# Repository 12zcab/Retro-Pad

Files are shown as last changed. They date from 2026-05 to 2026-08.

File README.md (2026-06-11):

# Retro-Pad
What happens if a keyboard can emulate Retro Stuff?
Yah its just a simple keyboard but include a 4inch tft and speaker for Retro Emulation and Designed for myself.

## Tinkercad Link
https://www.tinkercad.com/things/bjJYySNUwrn-blekeyboard-esp32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
## Zine Page Design
https://www.figma.com/design/CGgY6SRriEGCdJu8L95h5M/Retro-Pad-Zine-Page?node-id=0-1&t=7zGqFnisPlWxRSIn-1
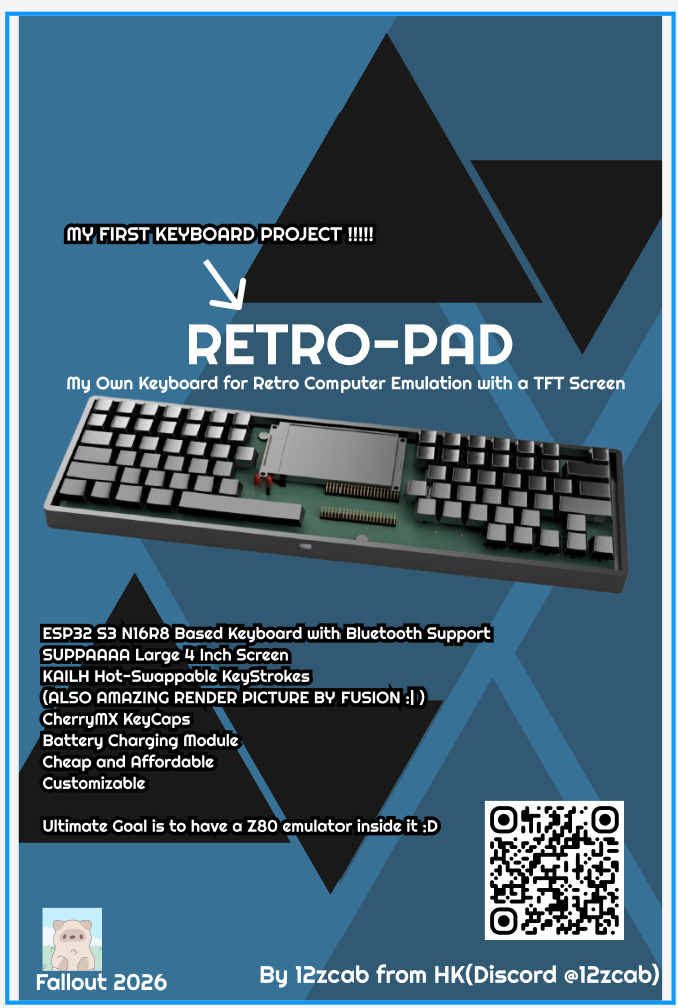
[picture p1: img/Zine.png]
Zine

## Images
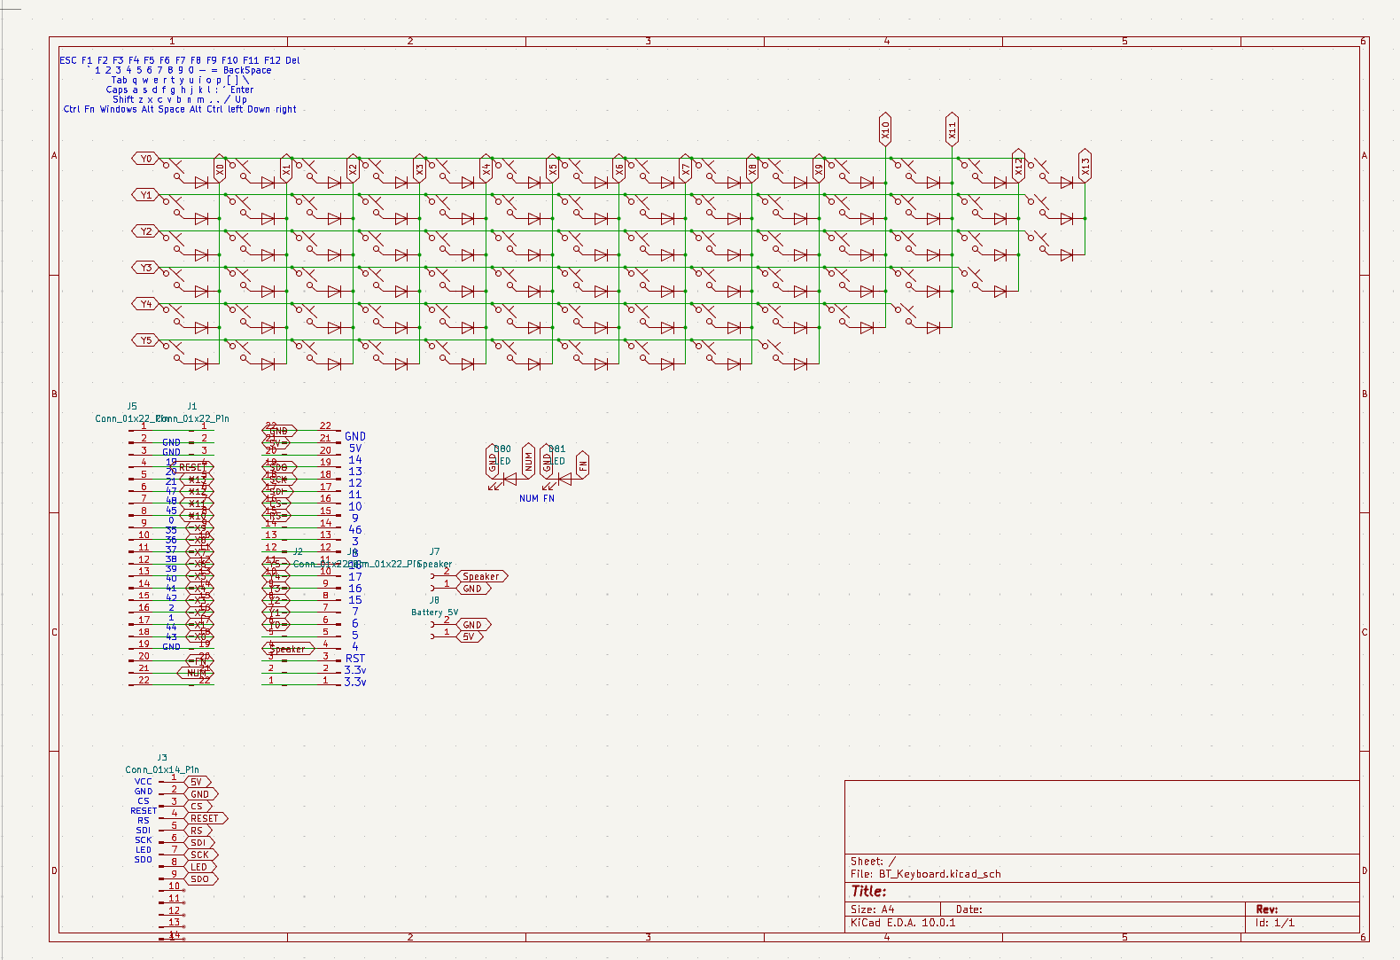
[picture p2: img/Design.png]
Design

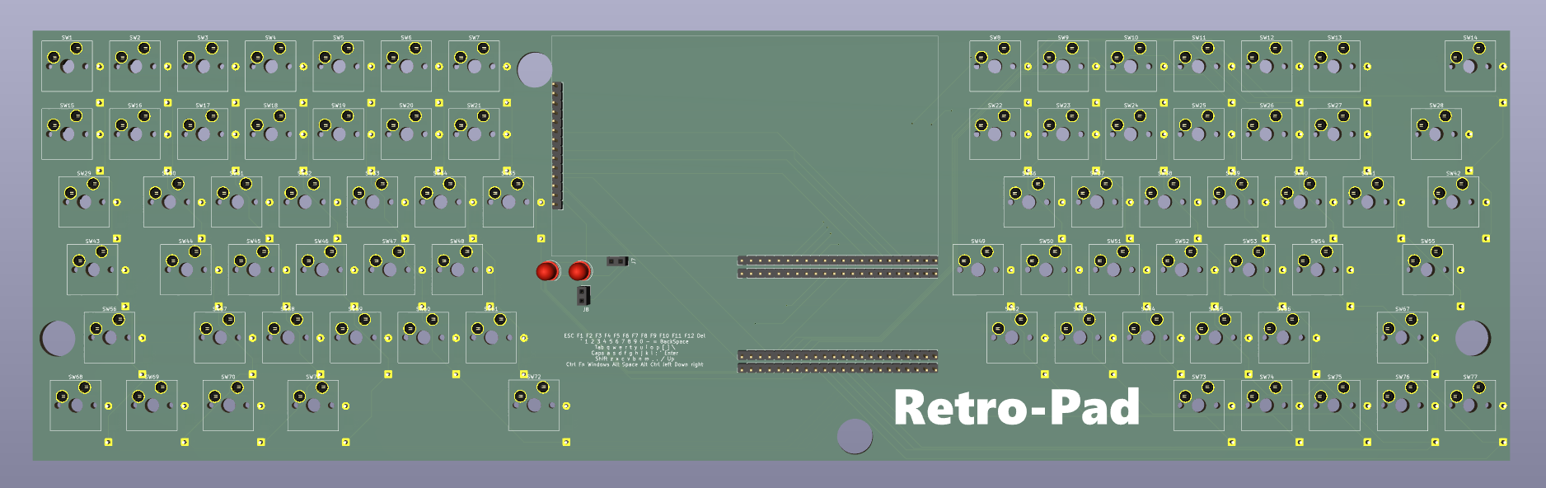
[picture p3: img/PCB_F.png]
PCB_F

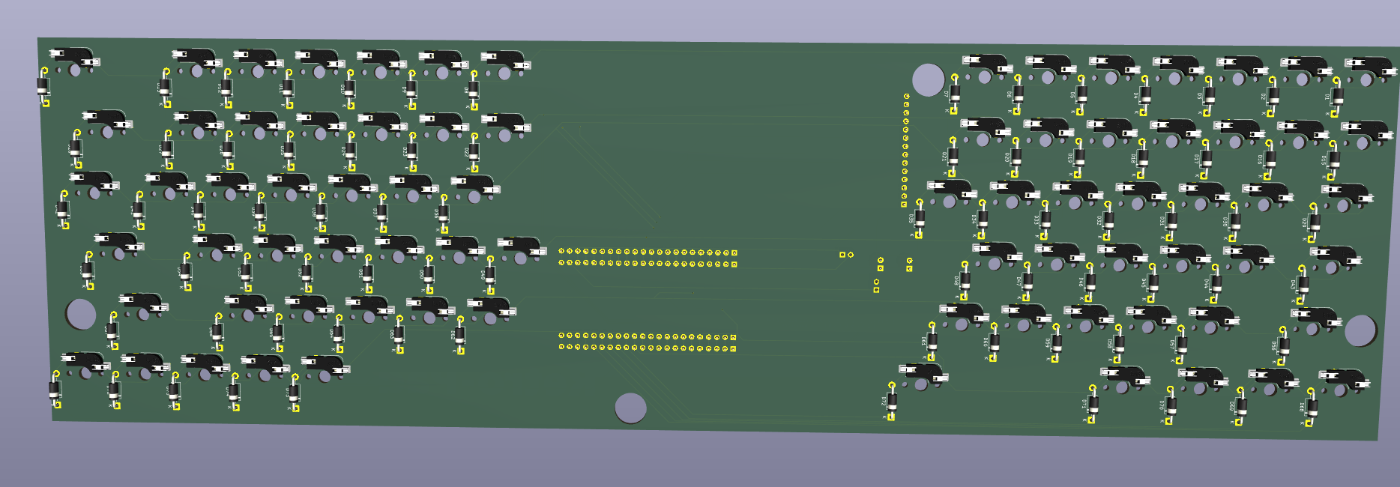
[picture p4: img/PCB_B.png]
PCB_B

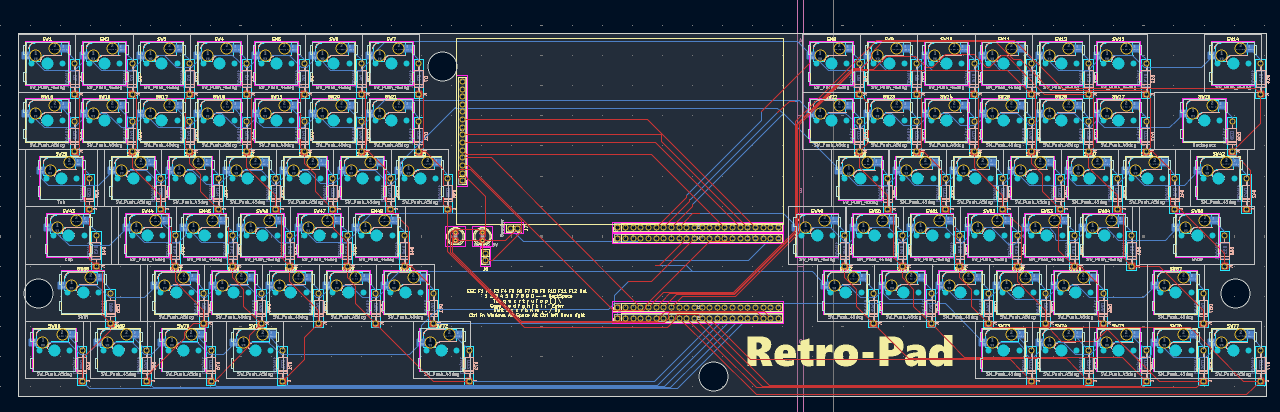
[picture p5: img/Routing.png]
Routing

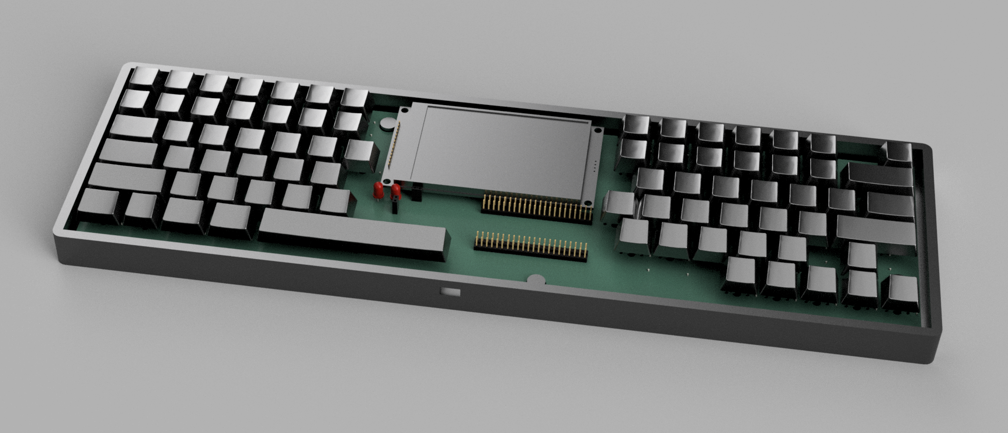
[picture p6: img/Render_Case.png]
Case


## Notes
Erm the Emulator Part is not yet programmed as i haven't build it irl yet
I will work on it as I receive the grant to buy the ESP32
Also as i like Looking at PCBs so the case will be really simple

## Why I build this?
1.My Current Keyboard is DUMB
2.I think i like the touch of the 高特(erm in direct translation, High Special) Keystrokes
3.I also like to emulate 8086 or z80s with my pi and keyboard and a hdmi screen but i realized a single esp32 could have done all things in a single PCB

## What it can do?
1.Bluetooth/USB keyboard support
2.Configurable Macro Support
3.Key Layout Remap Support
4.Emulate Z80 CP/M :D
5.may be also as a mini Piano?(Erm yah cuz why not?)

## Component List
(For More Details,Please Refer to the BOM.csv.)
| Name | SpecName | Usage | Quantities |
|---|---|---|---|
| KeyStrokes | For My Self,高特青軸 (im not sure what its called in english)| For the Switches on Keyboard!| 77 |
| KeyCaps | Cherry Key Caps | Key Caps that you press on | Depends |
| ESP32 MCU board | ESP32 S3 N16R8 | A controller board that handles the TFT screen display and Bluetooth Communication | 1 |
| TFT Screen | TFT 4inch Screen Module with 14 Pins | A medium size TFT that display the Emulated Content and also Let me reconfigure the Keyboard with GUI | 1 |
| KeyStroke Hot Swappable Sockets | Kailh KeyStroke Sockets | for HotSwappable KeyStrokes!!! | 77 |
| Speaker | 2W3718 Speaker Module | Play Some Funny Sounds with esp32 | 1 |
| LED for Fn and Caps Signal | 5mm diameter THT leds | to show if u have Caps and Fn enabled or disabled. | 2 |
| LiBattery 3.7V | No Specific Name,just any Li Battery that can fit into the case | Any Capacity u want,3000mah suggested | 1 |
| LiBattery 3.7v-5v Protector Board and Charger Board | same as the name | Protecting ur Li-ion Battery from exploding | 1 |

Also prepare some 2.54 Dupont Socket and PinHeaders incase if u may disassemble it or replace some modules.

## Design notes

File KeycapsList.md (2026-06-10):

## 3D printing List and Keycap List
| | R1 | R2 | R3 | R4 |
|---|---|---|---|---|
|U1|Fn Alt Ctrl ArrowL ArrowR ArrowD ZXCVBNM,./ ArrowU|ASDFGHJKL;'|QWERTYUIOP[]|`1234567890-= Esc F1-12 Delete|
|U1.25|Win Alt Ctrl||||
|U1.5|||Tab \||
|U1.75||Caps Lock|||
|U2||||BackSpace|
|U2.25|Shift|Enter|||
|U5.25|Space||||

| | R1 | R2 | R3 | R4 | SUM |
|---|---|---|---|---|---|
|U1|17|11|12|27|67|
|U1.25|3||||3|
|U1.5|||2||2|
|U1.75||1|||1|
|U2||||1|1|
|U2.25|1|1|||2|
|U5.25|1||||1|
|..|..|..|..|..|77|

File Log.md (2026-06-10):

Day1 2/5/2026

Targets:
1.Bluetooth Keyboard Support

2.Music Instrument

3.Simple 8086 or z80 Simulation (Hopefully)

https://github.com/ConstantinoSchillebeeckx/cherry-mx-keycaps

what i have done today:

1. generated the Keylayout.json and used the KB plugin in Kicad to Arrange the Layout of keys
2. decided how am i going to stream the HDMI screen to tft (through UVC and HDMI to USB Capture Card(i found some cheap one))
3. finished the simple Circuit in kicad and layouted some of them in Kicad

Day2 15/5/2026

Finished Kicad Layout and Routing

We will move on to the coding part next time:D

https://item.taobao.com/item.htm?ali\_refid=a3\_430008\_1006%3A1422310143%3AH%3A%2FWxXF5KEPDBl3HD6bqPRiwI%2Fqz1PRZed%3A7e8e3f8b5423678a1f3602527d140b2b\&ali\_trackid=283\_7e8e3f8b5423678a1f3602527d140b2b\&id=889327946362\&mi\_id=0000KfCYVAKBkDPFdWEk\_TIRsJP2s26MLFkTm8Ch3dcCHBo\&mm\_sceneid=1\_0\_1500450081\_0\&priceTId=2100c90417795207132815695e0cf9\&skuId=5917293894029\&spm=a21n57.1.hoverItem.2\&utparam=%7B%22aplus\_abtest%22%3A%2217b833b15ee66eaabd2b4353216af808%22%7D\&xxc=ad\_ztc

https://item.taobao.com/item.htm?abbucket=20\&id=892402646945\&mi\_id=00008PVZair30QEfFiEgqpUfwUhRiykNUhKd\_J1pzu8Z\_iA\&ns=1\&priceTId=2100cff417795213512193519e0d1d\&skuId=5908689555076\&spm=a21n57.1.hoverItem.11\&utparam=%7B%22aplus\_abtest%22%3A%22b225d9c1a26b6233dcdc5695b8bcce75%22%7D\&xxc=taobaoSearch

Day3 23/5/2026

Added the Speaker and Power Module.
Finished Routing the PCB and generated Gerber and Drill Files

Finished a Simple Firmware for testing

Day4 24/5/2026

Redesigned the PCB for Hot-Swappable Keystrokes and routed it.

Wrote some details for readme.md

Also finished the BOM

Rendered 3D image for the PCB

Exported Gerber Files

Exported PCB 3D files

Included the CherryMX KeyCaps from another repo
Erm i think my computer got some problem so i will finish the STL case next time

Day5 26/5/2026

Finished the basic case and also keycap amount table for R1-R4 and U1 to U5.25
Erm as my Space bar is only 5.25U sooooooo i hope it can work without stablizer
(Hopefulyl it will work like:  - _ )and not - \ :DDDDD anybody get it?

Day6 3/6/2026
Requirement Checklist:
1.Update the Photo in Figma DONE
2.Update all the PCB designs in GitHub   DONE
3.Add Zine Photo to Readme.md  DONE  
4.Add mounting holes for the PCB  DONE 
5.Make a Better Case with Fusion (with Text and rounded Edges and also mounting pins for positioning)  DONE

Day7 10/6/2026
Rendered the 3D image with Keycaps
Added Cost for BOM.csv
Resubmitting.

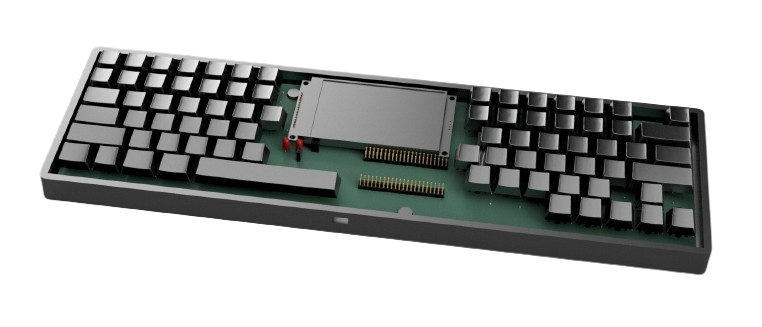
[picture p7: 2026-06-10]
img/RMBG.png

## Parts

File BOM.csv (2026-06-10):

Qty | Value | Link | Quantity Price | Total Item Price in RMB | Total Item Price in USD
77 | 1N4001 Diode | https://item.taobao.com/item.htm?ali_trackid=1_ac852f84a5ddb011c0c889d4550c7625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 | 0.03 | 2.31 | 0.3465
2 | LED | https://item.taobao.com/item.htm?ali_trackid=318_36dd7da80ac5a741d8252891407d112a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 | Not Appliable | 3.77 | 0.5655
1 | ESP32 S3 N16R8 | https://item.taobao.com/item.htm?id=810960494289&from=cart&skuId=5838973348963&upStreamPrice=2430 | 24.3 | 24.3 | 3.645
1 | 4Inch TFT Screen | https://item.taobao.com/item.htm?id=811840045954&from=cart&skuId=5675825499909&upStreamPrice=7542 | 75.62 | 75.62 | 11.343
1 | Speaker | https://item.taobao.com/item.htm?ali_trackid=283_7e8e3f8b5423678a1f3602527d140b2b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 | 5 | 5 | 0.75
1 | Battery 5V | https://item.taobao.com/item.htm?id=892402646945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 | 13 | 13 | 1.95
77 | KeyStroke | https://item.taobao.com/item.htm?id=626986550029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 | Not Appliable | 32.4 | 4.86
77 | KailH KeyStroke Holder | https://item.taobao.com/item.htm?id=633674488792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 | Not Appliable | 15 | 2.25
 | Sum Up |  |  |  | 25.71
 | Estimated Cost with Transporting Cost |  |  |  | 30.852

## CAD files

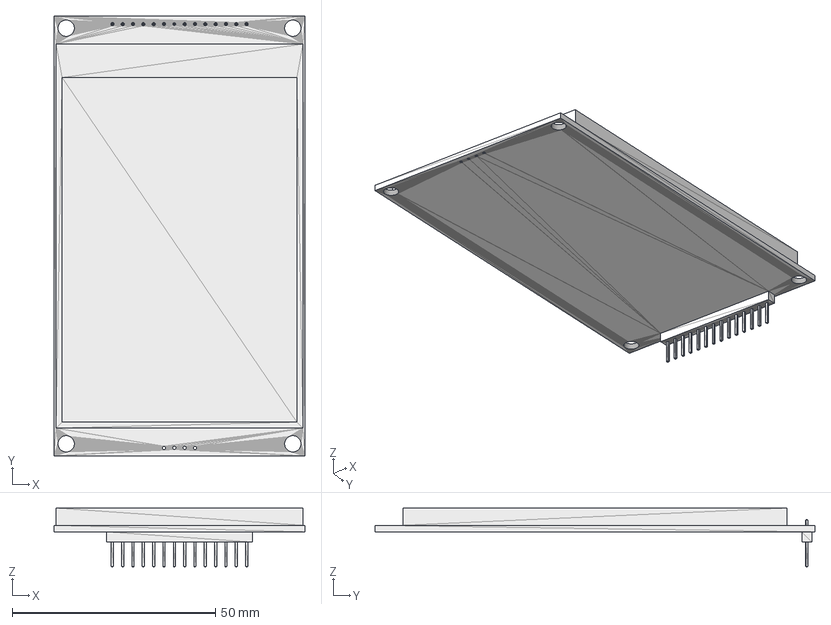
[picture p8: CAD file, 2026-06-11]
3Dmodels/4_0 inch tft.step
61.8 x 108.2 x 14.5 mm

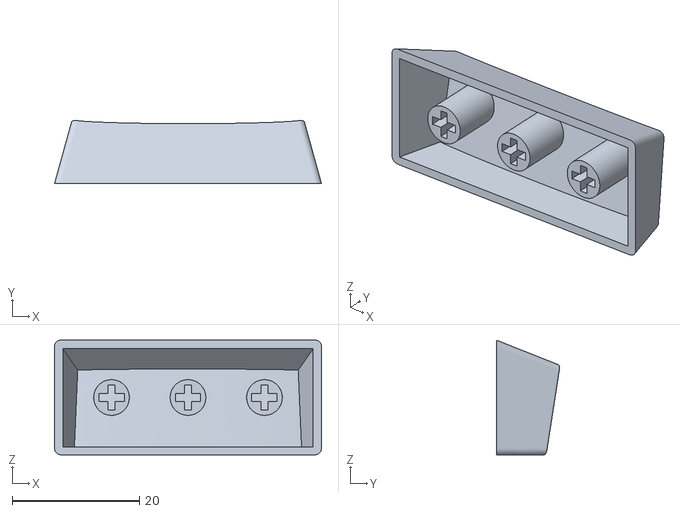
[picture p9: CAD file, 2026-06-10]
3Dmodels/Caps/1x2.25 R1.stl
41.9 x 9.89 x 18.0

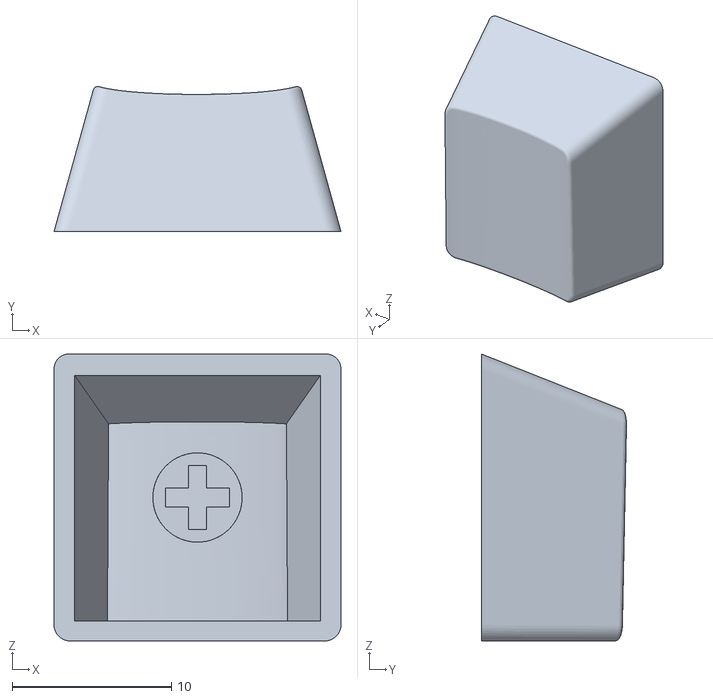
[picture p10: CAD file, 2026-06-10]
3Dmodels/Caps/1x1 R3.stl
18.0 x 9.09 x 18.0

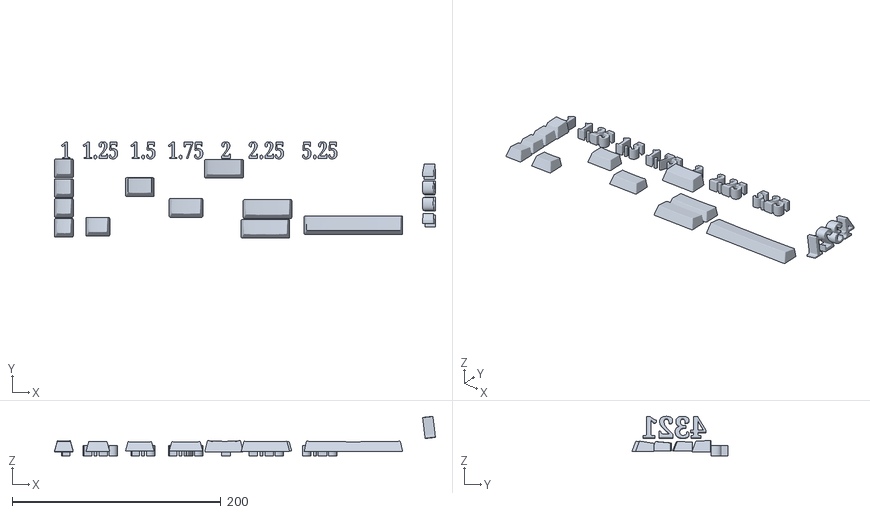
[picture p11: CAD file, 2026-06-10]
3Dmodels/KeyCaps.stl
365.4 x 92.5 x 37.9

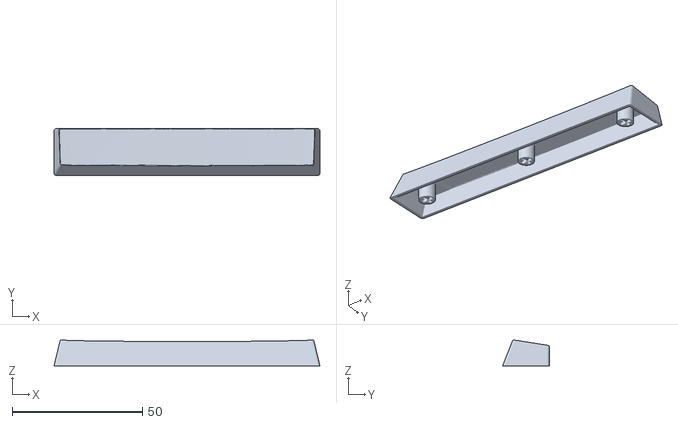
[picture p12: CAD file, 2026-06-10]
3Dmodels/Caps/1x5.25 R1.stl
102.1 x 18.0 x 9.95

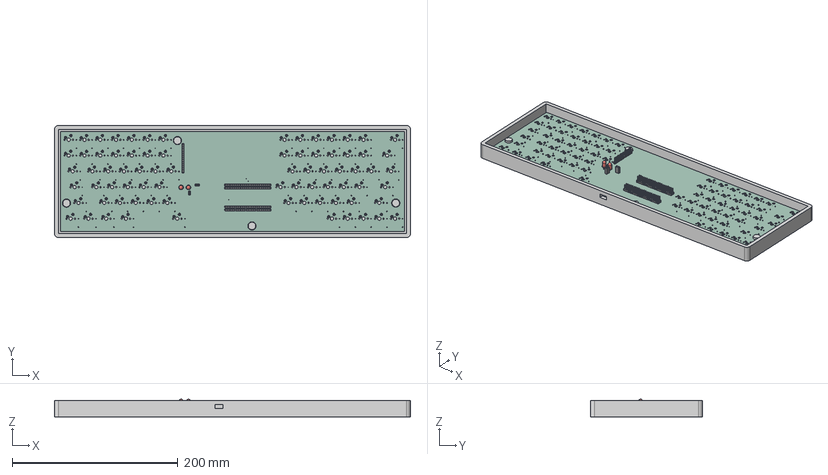
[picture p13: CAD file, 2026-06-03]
3Dmodels/Case.step
429.8 x 135.7 x 21.5 mm
PinSocket_1x02_P2.54mm_Vertical x 2
PinHeader_1x14_P2.54mm_Vertical
LED_D5.0mm x 2
PinHeader_1x22_P2.54mm_Vertical x 4
BT_Keyboard_PCB
D_DO-41_SOD81_P10.16mm_Horizontal x 77
SW_Hotswap_Kailh_MX x 77

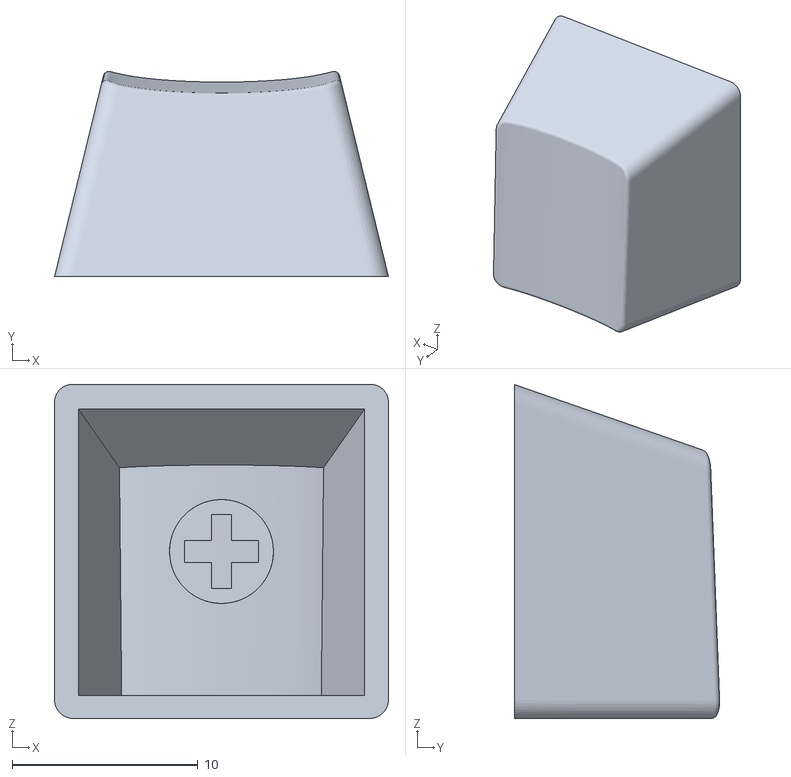
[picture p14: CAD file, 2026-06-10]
3Dmodels/Caps/1x1 R4.stl
18.0 x 11.1 x 18.0

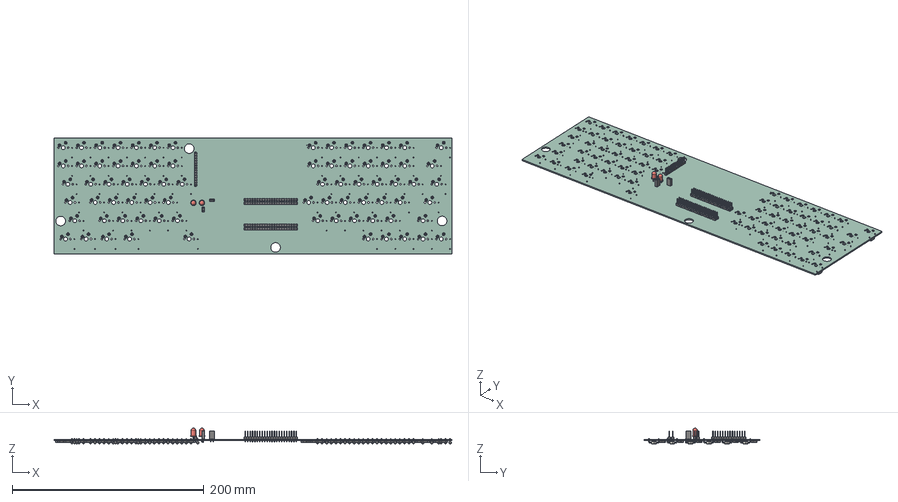
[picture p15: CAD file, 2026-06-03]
3Dmodels/pcb.step
414.8 x 120.7 x 16.5 mm
SW_Hotswap_Kailh_MX x 77
PinSocket_1x02_P2.54mm_Vertical x 2
PinHeader_1x14_P2.54mm_Vertical
LED_D5.0mm x 2
PinHeader_1x22_P2.54mm_Vertical x 4
D_DO-41_SOD81_P10.16mm_Horizontal x 77
BT_Keyboard_PCB

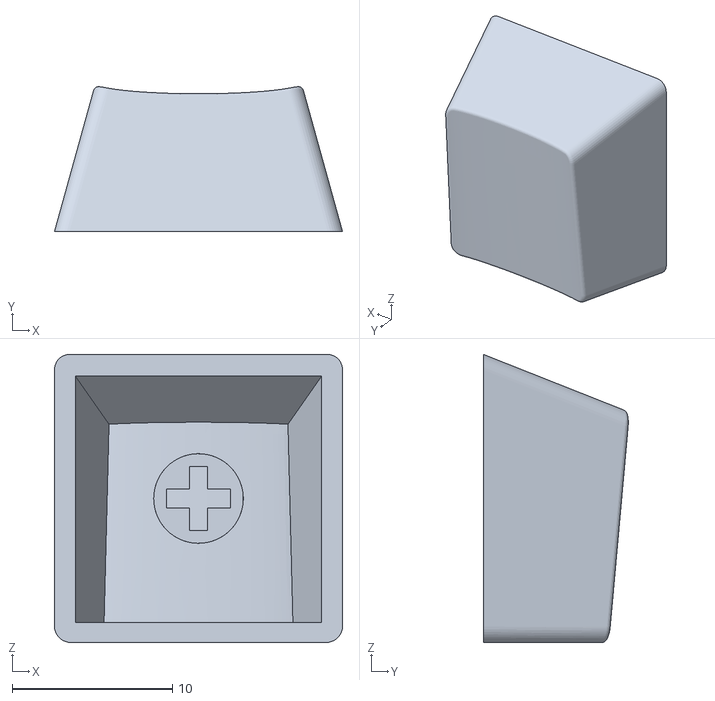
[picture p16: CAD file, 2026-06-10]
3Dmodels/Caps/1x1 R2.stl
18.0 x 9.04 x 18.0

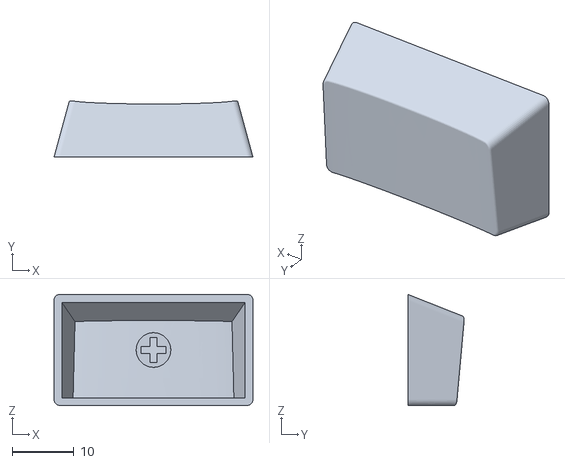
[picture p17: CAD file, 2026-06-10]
3Dmodels/Caps/1x1.75 R2.stl
32.2 x 9.10 x 18.0

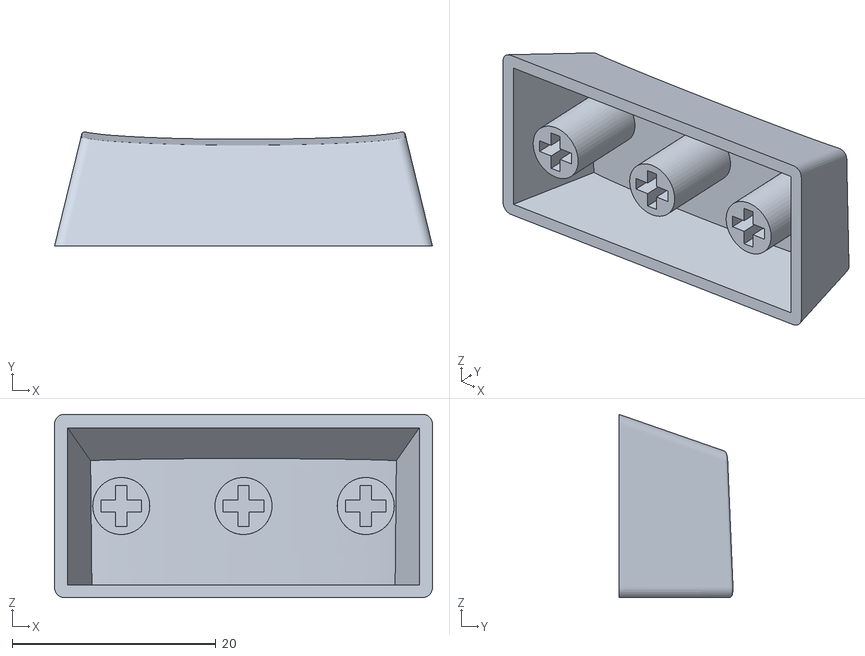
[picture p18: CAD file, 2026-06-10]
3Dmodels/Caps/1x2 R4.stl
37.1 x 11.2 x 18.0

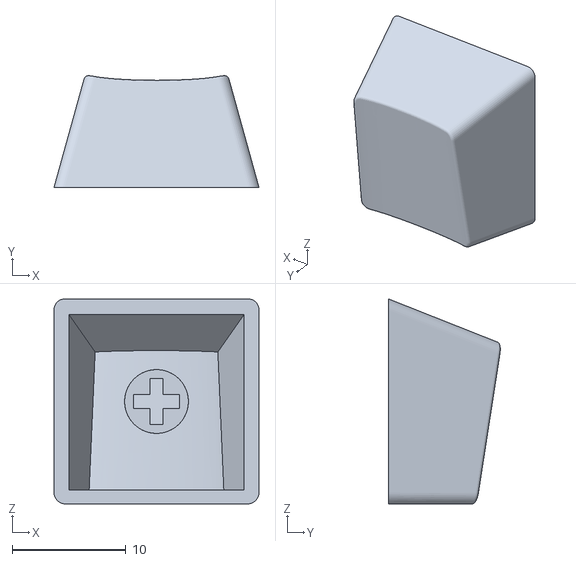
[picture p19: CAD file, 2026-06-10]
3Dmodels/Caps/1x1 R1.stl
18.0 x 9.80 x 18.0

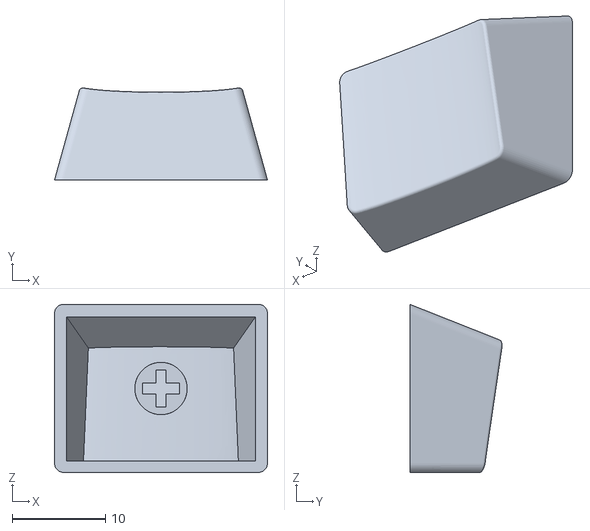
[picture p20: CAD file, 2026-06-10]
3Dmodels/Caps/1x1.25 R1.stl
22.8 x 9.84 x 18.0

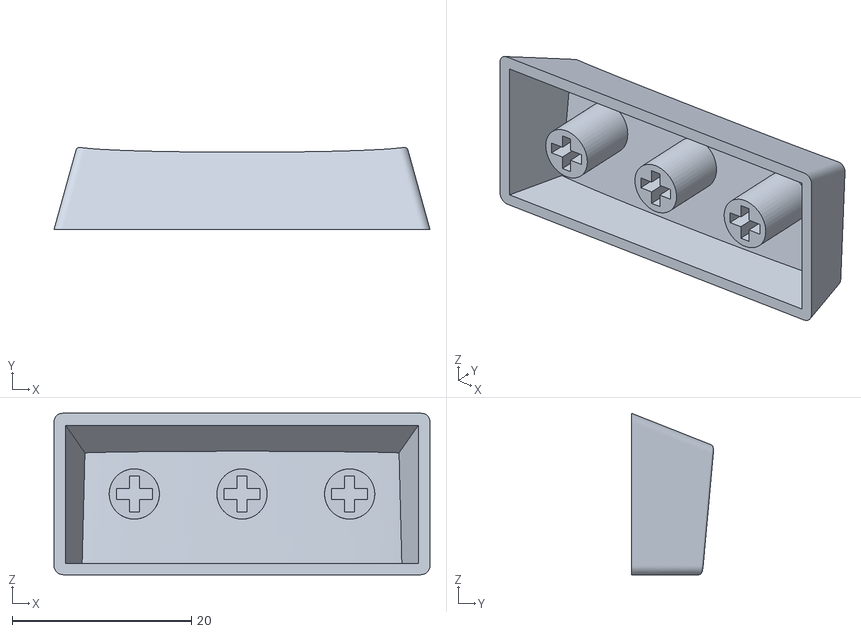
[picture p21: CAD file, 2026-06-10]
3Dmodels/Caps/1x2.25 R2.stl
41.9 x 9.12 x 18.0

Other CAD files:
3Dmodels/Caps/1x1.5 R3.stl
3Dmodels/4_0 inch tft.stl

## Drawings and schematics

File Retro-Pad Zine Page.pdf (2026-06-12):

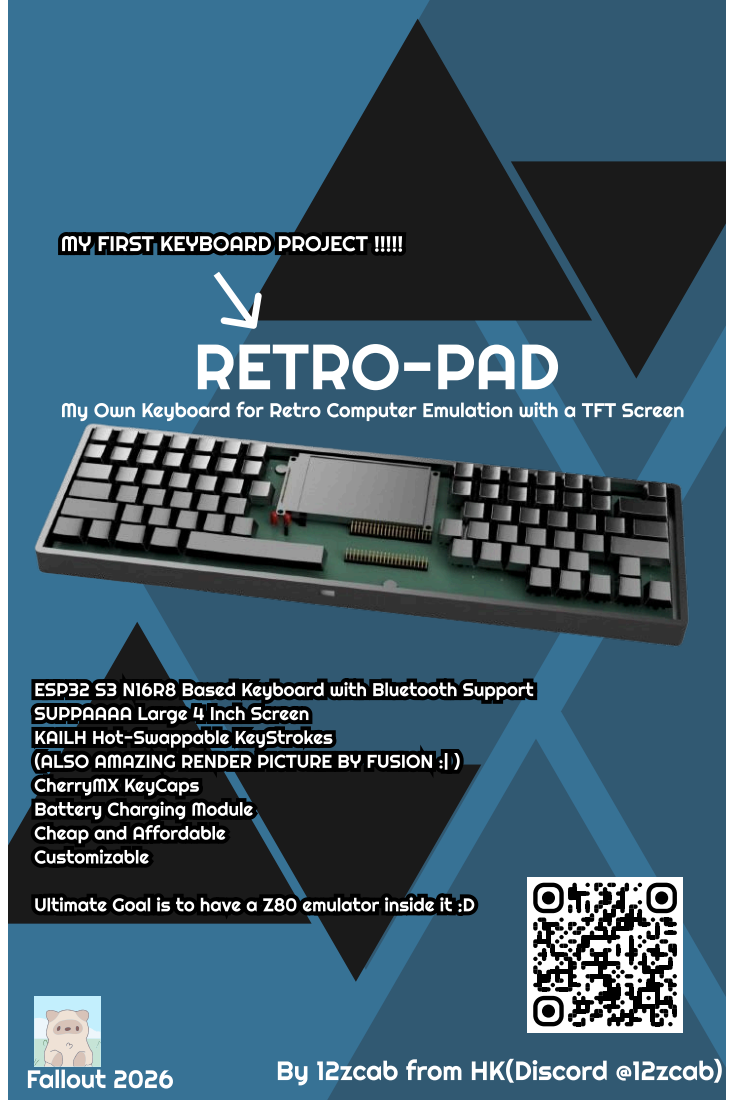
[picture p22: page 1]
Fallout 2026; RETRO-PAD

MY FIRST KEYBOARD PROJECT !!!!!

My Own Keyboard for Retro Computer Emulation with a TFT Screen

ESP32 S3 N16R8 Based Keyboard with Bluetooth Support
SUPPAAAA Large 4 Inch Screen
KAILH Hot-Swappable KeyStrokes
(ALSO AMAZING RENDER PICTURE BY FUSION :| )
CherryMX KeyCaps
Battery Charging Module
Cheap and Affordable
Customizable

Ultimate Goal is to have a Z80 emulator inside it :D

By 12zcab from HK(Discord @12zcab)

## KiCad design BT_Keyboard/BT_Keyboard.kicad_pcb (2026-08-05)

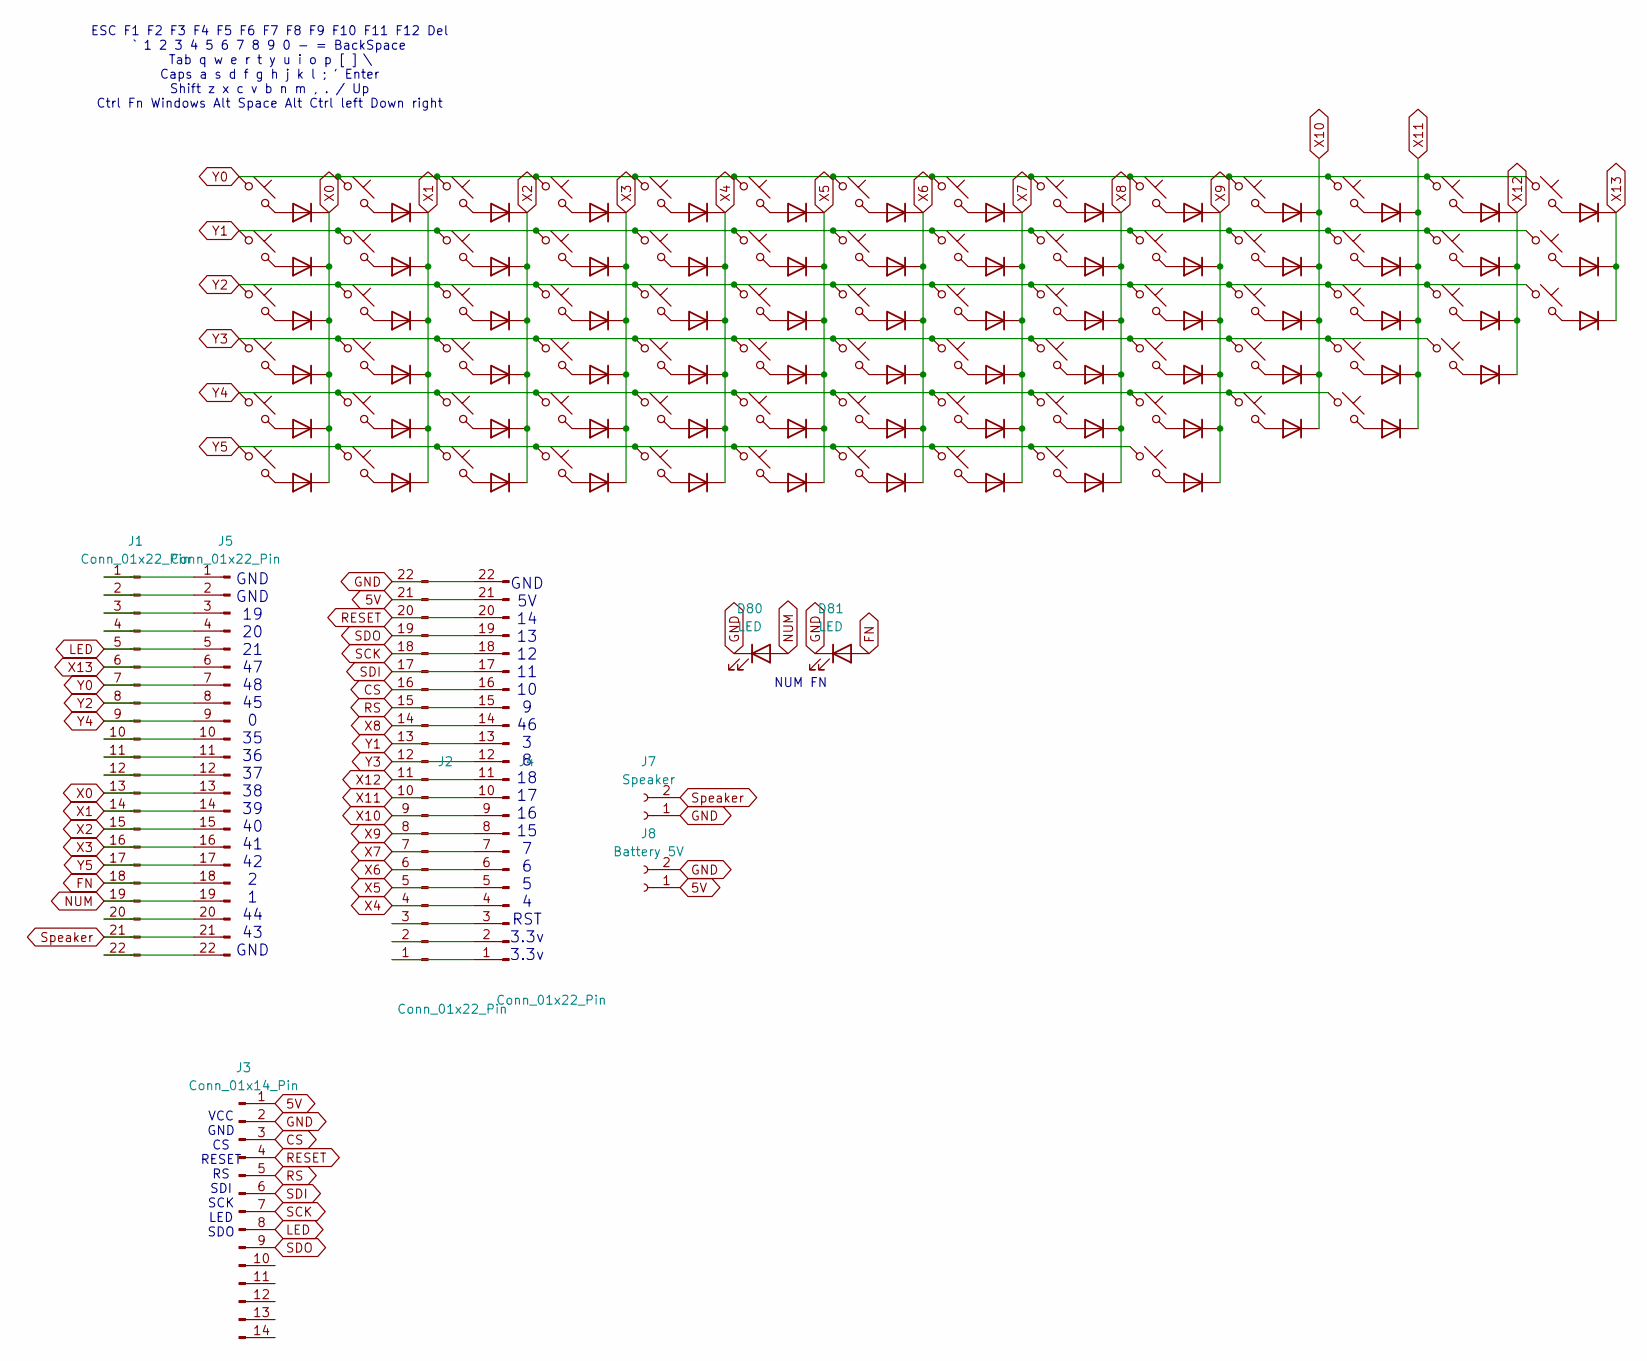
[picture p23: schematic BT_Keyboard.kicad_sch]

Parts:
D1, D2, D3, D4, D5, D6, D7, D8, D9, D10, D11, D12, D13, D14, D15, D16, D17, D18, D19, D20, D21, D22, D23, D24, D25, D26, D27, D28, D29, D30, D31, D32, D33, D34, D35, D36, D37, D38, D39, D40, D41, D42, D43, D44, D45, D46, D47, D48, D49, D50, D51, D52, D53, D54, D55, D56, D57, D58, D59, D60, D61, D62, D63, D64, D65, D66, D67, D68, D69, D70, D71, D72, D73, D74, D75, D76, D77: 1N4001; D_DO-41_SOD81_P10.16mm_Horizontal
D80, D81: LED; LED_D5.0mm
J1, J2, J4, J5: Conn_01x22_Pin; PinHeader_1x22_P2.54mm_Vertical
J3: Conn_01x14_Pin; PinHeader_1x14_P2.54mm_Vertical
J7: Speaker; PinSocket_1x02_P2.54mm_Vertical
J8: Battery 5V; PinSocket_1x02_P2.54mm_Vertical
SW1, SW2, SW3, SW4, SW5, SW6, SW7, SW8, SW9, SW10, SW11, SW12, SW13, SW14, SW15, SW16, SW17, SW18, SW19, SW20, SW21, SW22, SW23, SW24, SW25, SW26, SW27, SW30, SW31, SW32, SW33, SW34, SW35, SW36, SW37, SW38, SW39, SW40, SW41, SW42, SW44, SW45, SW46, SW47, SW48, SW49, SW50, SW51, SW52, SW53, SW54, SW57, SW58, SW59, SW60, SW61, SW62, SW63, SW64, SW65, SW66, SW67, SW68, SW69, SW70, SW71, SW72, SW73, SW74, SW75, SW76, SW77: SW_Push_45deg; SW_Hotswap_Kailh_MX_Plated_1.00u
SW28: Backspace; SW_Hotswap_Kailh_MX_Plated_1.75u
SW29: Tab; SW_Hotswap_Kailh_MX_Plated_1.25u
SW43: Cap; SW_Hotswap_Kailh_MX_Plated_1.50u
SW55: Enter; SW_Hotswap_Kailh_MX_Plated_2.00u
SW56: Shift; SW_Hotswap_Kailh_MX_Plated_2.00u

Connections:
5V: J2.21, J3.1, J4.21, J8.1
CS: J2.16, J3.3, J4.16
FN: D81.2 (A), J1.18, J5.18
GND: D80.1 (K), D81.1 (K), J2.22, J3.2, J4.22, J7.1, J8.2
LED: J1.5, J3.8, J5.5
NUM: D80.2 (A), J1.19, J5.19
unnamed: D1.2 (A), SW1.2
unnamed: D2.2 (A), SW2.2
unnamed: D3.2 (A), SW3.2
unnamed: D4.2 (A), SW4.2
unnamed: D5.2 (A), SW5.2
unnamed: D6.2 (A), SW6.2
unnamed: D7.2 (A), SW7.2
unnamed: D8.2 (A), SW8.2
unnamed: D9.2 (A), SW9.2
unnamed: D10.2 (A), SW10.2
unnamed: D11.2 (A), SW11.2
unnamed: D12.2 (A), SW12.2
unnamed: D13.2 (A), SW13.2
unnamed: D14.2 (A), SW14.2
unnamed: D15.2 (A), SW15.2
unnamed: D16.2 (A), SW16.2
unnamed: D17.2 (A), SW17.2
unnamed: D18.2 (A), SW18.2
unnamed: D19.2 (A), SW19.2
unnamed: D20.2 (A), SW20.2
unnamed: D21.2 (A), SW21.2
unnamed: D22.2 (A), SW22.2
unnamed: D23.2 (A), SW23.2
unnamed: D24.2 (A), SW24.2
unnamed: D25.2 (A), SW25.2
unnamed: D26.2 (A), SW26.2
unnamed: D27.2 (A), SW27.2
unnamed: D28.2 (A), SW28.2
unnamed: D29.2 (A), SW29.2
unnamed: D30.2 (A), SW30.2
unnamed: D31.2 (A), SW31.2
unnamed: D32.2 (A), SW32.2
unnamed: D33.2 (A), SW33.2
unnamed: D34.2 (A), SW34.2
unnamed: D35.2 (A), SW35.2
unnamed: D36.2 (A), SW36.2
unnamed: D37.2 (A), SW37.2
unnamed: D38.2 (A), SW38.2
unnamed: D39.2 (A), SW39.2
unnamed: D40.2 (A), SW40.2
unnamed: D41.2 (A), SW41.2
unnamed: D42.2 (A), SW42.2
unnamed: D43.2 (A), SW43.2
unnamed: D44.2 (A), SW44.2
unnamed: D45.2 (A), SW45.2
unnamed: D46.2 (A), SW46.2
unnamed: D47.2 (A), SW47.2
unnamed: D48.2 (A), SW48.2
unnamed: D49.2 (A), SW49.2
unnamed: D50.2 (A), SW50.2
unnamed: D51.2 (A), SW51.2
unnamed: D52.2 (A), SW52.2
unnamed: D53.2 (A), SW53.2
unnamed: D54.2 (A), SW54.2
unnamed: D55.2 (A), SW55.2
unnamed: D56.2 (A), SW56.2
unnamed: D57.2 (A), SW57.2
unnamed: D58.2 (A), SW58.2
unnamed: D59.2 (A), SW59.2
unnamed: D60.2 (A), SW60.2
unnamed: D61.2 (A), SW61.2
unnamed: D62.2 (A), SW62.2
unnamed: D63.2 (A), SW63.2
unnamed: D64.2 (A), SW64.2
unnamed: D65.2 (A), SW65.2
unnamed: D66.2 (A), SW66.2
unnamed: D67.2 (A), SW67.2
unnamed: D68.2 (A), SW68.2
unnamed: D69.2 (A), SW69.2
unnamed: D70.2 (A), SW70.2
unnamed: D71.2 (A), SW71.2
unnamed: D72.2 (A), SW72.2
unnamed: D73.2 (A), SW73.2
unnamed: D74.2 (A), SW74.2
unnamed: D75.2 (A), SW75.2
unnamed: D76.2 (A), SW76.2
unnamed: D77.2 (A), SW77.2
unnamed: J1.1, J5.1
unnamed: J1.2, J5.2
unnamed: J1.3, J5.3
unnamed: J1.4, J5.4
unnamed: J1.10, J5.10
unnamed: J1.11, J5.11
unnamed: J1.12, J5.12
unnamed: J1.20, J5.20
unnamed: J1.22, J5.22
unnamed: J2.1, J4.1
unnamed: J2.2, J4.2
unnamed: J2.3, J4.3
RESET: J2.20, J3.4, J4.20
RS: J2.15, J3.5, J4.15
SCK: J2.18, J3.7, J4.18
SDI: J2.17, J3.6, J4.17
SDO: J2.19, J3.9, J4.19
Speaker: J1.21, J5.21, J7.2
X0: D1.1 (K), D15.1 (K), D29.1 (K), D43.1 (K), D56.1 (K), D68.1 (K), J1.13, J5.13
X1: D2.1 (K), D16.1 (K), D30.1 (K), D44.1 (K), D57.1 (K), D69.1 (K), J1.14, J5.14
X2: D3.1 (K), D17.1 (K), D31.1 (K), D45.1 (K), D58.1 (K), D70.1 (K), J1.15, J5.15
X3: D4.1 (K), D18.1 (K), D32.1 (K), D46.1 (K), D59.1 (K), D71.1 (K), J1.16, J5.16
X4: D5.1 (K), D19.1 (K), D33.1 (K), D47.1 (K), D60.1 (K), D72.1 (K), J2.4, J4.4
X5: D6.1 (K), D20.1 (K), D34.1 (K), D48.1 (K), D61.1 (K), D73.1 (K), J2.5, J4.5
X6: D7.1 (K), D21.1 (K), D35.1 (K), D49.1 (K), D62.1 (K), D74.1 (K), J2.6, J4.6
X7: D8.1 (K), D22.1 (K), D36.1 (K), D50.1 (K), D63.1 (K), D75.1 (K), J2.7, J4.7
X8: D9.1 (K), D23.1 (K), D37.1 (K), D51.1 (K), D64.1 (K), D76.1 (K), J2.14, J4.14
X9: D10.1 (K), D24.1 (K), D38.1 (K), D52.1 (K), D65.1 (K), D77.1 (K), J2.8, J4.8
X10: D11.1 (K), D25.1 (K), D39.1 (K), D53.1 (K), D66.1 (K), J2.9, J4.9
X11: D12.1 (K), D26.1 (K), D40.1 (K), D54.1 (K), D67.1 (K), J2.10, J4.10
X12: D13.1 (K), D27.1 (K), D41.1 (K), D55.1 (K), J2.11, J4.11
X13: D14.1 (K), D28.1 (K), D42.1 (K), J1.6, J5.6
Y0: J1.7, J5.7, SW1.1, SW2.1, SW3.1, SW4.1, SW5.1, SW6.1, SW7.1, SW8.1, SW9.1, SW10.1, SW11.1, SW12.1, SW13.1, SW14.1
Y1: J2.13, J4.13, SW15.1, SW16.1, SW17.1, SW18.1, SW19.1, SW20.1, SW21.1, SW22.1, SW23.1, SW24.1, SW25.1, SW26.1, SW27.1, SW28.1
Y2: J1.8, J5.8, SW29.1, SW30.1, SW31.1, SW32.1, SW33.1, SW34.1, SW35.1, SW36.1, SW37.1, SW38.1, SW39.1, SW40.1, SW41.1, SW42.1
Y3: J2.12, J4.12, SW43.1, SW44.1, SW45.1, SW46.1, SW47.1, SW48.1, SW49.1, SW50.1, SW51.1, SW52.1, SW53.1, SW54.1, SW55.1
Y4: J1.9, J5.9, SW56.1, SW57.1, SW58.1, SW59.1, SW60.1, SW61.1, SW62.1, SW63.1, SW64.1, SW65.1, SW66.1, SW67.1
Y5: J1.17, J5.17, SW68.1, SW69.1, SW70.1, SW71.1, SW72.1, SW73.1, SW74.1, SW75.1, SW76.1, SW77.1

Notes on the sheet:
NUM FN
GND GND 19 20 21 47 48 45 0 35 36 37 38 39 40 41 42 2 1 44 43 GND
ESC F1 F2 F3 F4 F5 F6 F7 F8 F9 F10 F11 F12 Del ` 1 2 3 4 5 6 7 8 9 0 - = BackSpace Tab q w e r t y u i o p [ ] \ Caps a s d f g h j k l ; ' Enter Shift z x c v b n m , . / Up Ctrl Fn Windows Alt Space Alt Ctrl left Down right
VCC GND CS RESET RS SDI SCK LED SDO
GND 5V 14 13 12 11 10 9 46 3 8 18 17 16 15 7 6 5 4 RST 3.3v 3.3v

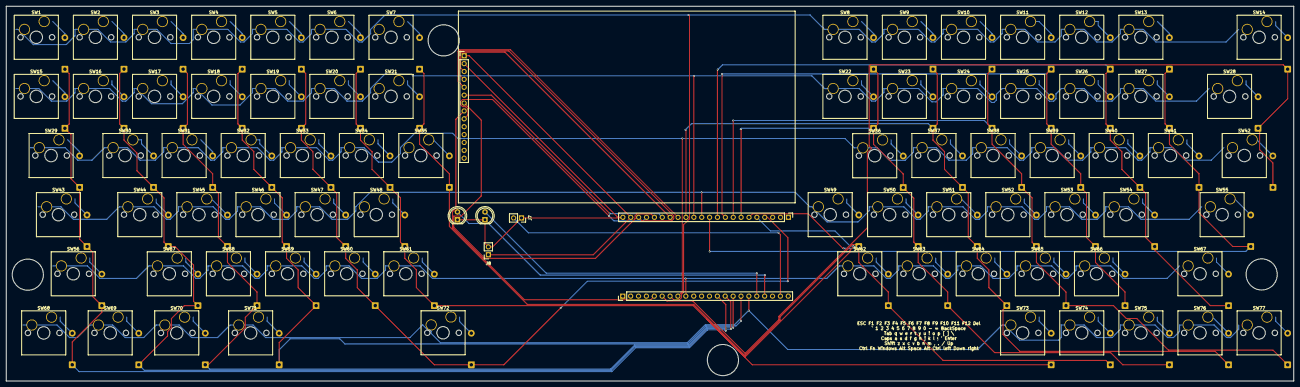
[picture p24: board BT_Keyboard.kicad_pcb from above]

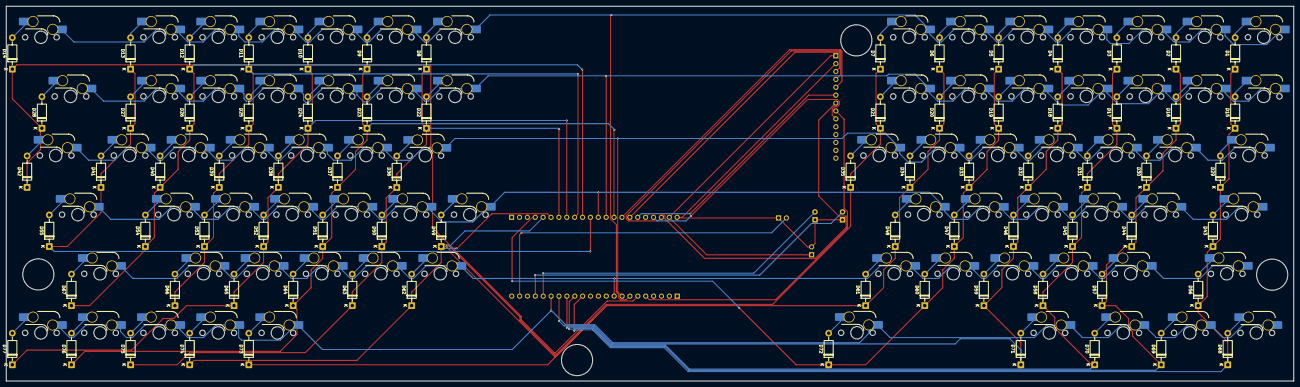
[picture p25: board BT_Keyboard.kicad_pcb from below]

Board: 2 copper layers, 414.8 x 120.7 mm, 161 parts (77 on the bottom side), 109 nets.

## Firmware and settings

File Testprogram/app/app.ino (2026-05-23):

#include <HijelHID_BLEKeyboard.h>

const byte ROW_PINS[] = {6,7,15,16,17,18};
const byte COL_PINS[] = {2,42,41,40,39,38,37,36,35,0,45,48,47,21};

const int ROW_COUNT = sizeof(ROW_PINS);
const int COL_COUNT = sizeof(COL_PINS);

unsigned char keymap[ROW_COUNT][COL_COUNT] = {
    {KEY_ESCAPE, KEY_F1, KEY_F2, KEY_F3, KEY_F4, KEY_F5, KEY_F6, KEY_F7, KEY_F8, KEY_F9, KEY_F10, KEY_F11, KEY_F12, KEY_DELETE},
    {KEY_GRAVE, KEY_1, KEY_2, KEY_3, KEY_4, KEY_5, KEY_6, KEY_7, KEY_8, KEY_9, KEY_0, KEY_MINUS, KEY_EQUAL, KEY_BACKSPACE},
    {KEY_TAB, KEY_Q, KEY_W, KEY_E, KEY_R, KEY_T, KEY_Y, KEY_U, KEY_I, KEY_O, KEY_P, KEY_LEFT_BRACE, KEY_RIGHT_BRACE, KEY_BACKSLASH},
    {KEY_CAPS_LOCK, KEY_A, KEY_S, KEY_D, KEY_F, KEY_G, KEY_H, KEY_J, KEY_K, KEY_L, KEY_SEMICOLON, KEY_APOSTROPHE, KEY_ENTER, 0},
    {KEY_LEFT_SHIFT, KEY_Z, KEY_X, KEY_C, KEY_V, KEY_B, KEY_N, KEY_M, KEY_COMMA, KEY_PERIOD, KEY_SLASH, KEY_UP, 0, 0},
    {KEY_LEFT_CTRL, KEY_FN, KEY_LEFT_GUI, KEY_LEFT_ALT, KEY_SPACE, KEY_RIGHT_ALT, KEY_RIGHT_CTRL, KEY_LEFT, KEY_DOWN, KEY_RIGHT, 0, 0, 0, 0}
};

bool keyStates[ROW_COUNT][COL_COUNT];

HijelHID_BLEKeyboard keyboard("Matrix Keyboard", "MyESP32S3", 100);

void setup() {
  Serial.begin(115200);
  for (int r = 0; r < ROW_COUNT; r++) {
    pinMode(ROW_PINS[r], INPUT);
  }
  for (int c = 0; c < COL_COUNT; c++) {
    pinMode(COL_PINS[c], INPUT_PULLUP);
  }
  Serial.println("Starting BLE work!");
  keyboard.begin();
}

void loop() {
  if (keyboard.isConnected()) {
    scanMatrix();
  }
  delay(10);
}

void scanMatrix() {
  for (int r = 0; r < ROW_COUNT; r++) {
    pinMode(ROW_PINS[r], OUTPUT);
    digitalWrite(ROW_PINS[r], LOW);

    for (int c = 0; c < COL_COUNT; c++) {
      bool currentState = (digitalRead(COL_PINS[c]) == LOW);
      if (currentState != keyStates[r][c]) {
        keyStates[r][c] = currentState;

        char key = keymap[r][c];
        if (key != 0) {
          if (currentState) {
            Serial.print("Pressed: ");
            Serial.println(key);
            keyboard.press(key);
          } else {
            Serial.print("Released: ");
            Serial.println(key);
            keyboard.release(key);
          }
        }
      }
    }
    pinMode(ROW_PINS[r], INPUT);
  }
}

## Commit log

2026-06-10 Add 3D printing and keycap list to KeycapsList.md
2026-06-11 Update and rename KeyCaps.stl.is.larger.than.25.mb.i.really.cant.upload.pls.forgive.me to KeyCaps.step.is.larger.than.25.mb.i.really.cant.upload.pls.forgive.me
